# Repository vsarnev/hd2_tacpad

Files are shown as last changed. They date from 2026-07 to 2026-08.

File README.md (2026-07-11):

# HD2 Tacpad

> ***"Stratagems primed. For Super Earth. For Managed Democracy."***

A working **HELLDIVERS™ 2 Stratagem Tacpad**: a cosplay prop that's also a real stratagem input device. Punch your codes into the touchscreen and the Tacpad transmits them to your PC as keyboard input, complete with the sound effects, team voice callouts, and a **"REQUEST RECEIVED"** call-in reveal straight off the front lines.

Built on an affordable ESP32-S3 touchscreen, it pairs over **Bluetooth** as a wireless keyboard. It's an actual stratagem macropad that *also* looks the part strapped to your wrist on the drop.

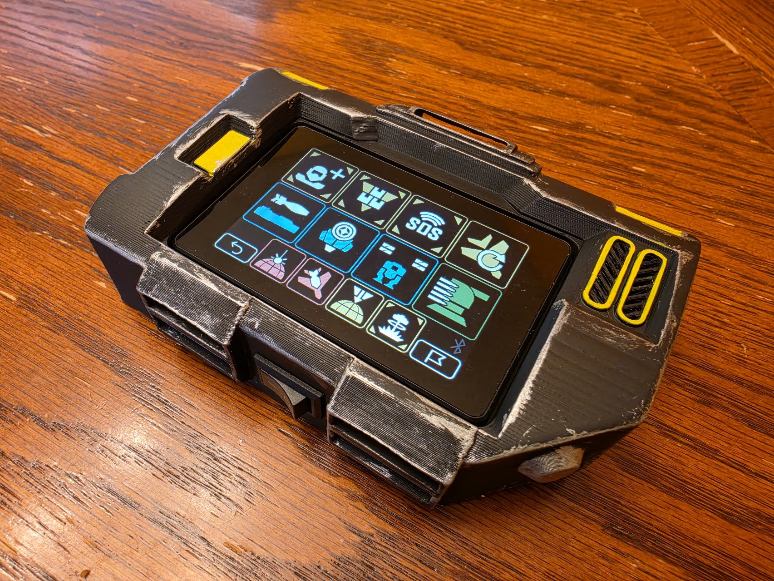
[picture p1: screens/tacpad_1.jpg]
The Tacpad


> [!NOTE]
> This is a **fork** of [unic8s/hd2_macropad](https://github.com/unic8s/hd2_macropad); see [Lineage & Credits](#lineage--credits). It runs on the specific device [JC3248W535](https://www.aliexpress.com/item/1005007566332450.html?) (a 3.5" ESP32-S3 QSPI touchscreen).
>
> **The assembled Tacpad connects over Bluetooth only**, since the enclosure covers the board's USB-C port. The firmware keeps USB support (inherited from the base project) for use on the bare board, e.g. for flashing.

## Contents

- [What this fork adds](#what-this-fork-adds)
- [Lineage & Credits](#lineage--credits)
- **Build Guide**
  - [1. Bill of Materials](#1-bill-of-materials)
  - [2. 3D Printed Parts](#2-3d-printed-parts)
  - [3. Electronics & Wiring](#3-electronics--wiring)
  - [4. Firmware](#4-firmware)
  - [5. Assembly](#5-assembly)
  - [6. Finished](#6-finished)
- [Get the game](#get-the-game) · [Disclaimer](#disclaimer)

---

## What this fork adds

Everything from the base firmware, plus a full front-line immersion layer:

- 🔊 **Helldivers SFX throughout.** Directional arrow tones, stratagem-prime cue, menu open/close, tab swipes. The original macropad sounds are swapped for in-universe audio.
- 📡 **Team voice callouts.** Your Super Destroyer and Eagle-1 announce stratagems by category with randomized lines, triggered on the call-in, exactly like in the field.
- 🖥️ **"REQUEST RECEIVED" call-in screen.** A full-screen reveal (icon + name) every time a stratagem is dispatched.
- 🎯 **Manual arm-mode input.** Hold the centre d-pad toggle to *open the stratagem menu* (it holds Ctrl on the host), then tap your code on the arrows. Each valid input is sent **live**, so the in-game menu builds as you type; complete a valid code and it throws + auto-disarms.
- ⚡ **Crisp, reliable touch input.** The panel's phantom double-taps are fixed at the source, so codes register cleanly even when spammed fast.
- 🔈 **Volume control** in settings and loudness-normalized audio across every cue and voice line.
- 🔋 **Battery level indicator.** For a LiPo-powered build, a battery icon + % up top and a voltage readout with on-device calibration, read through the ESP32's ADC.

Loadout selection, presets, user icons, cooldown tracking, ship-module modifiers, and BLE/USB switching all carry over from the base firmware.

---

## Lineage & Credits

This project stands on the shoulders of prior democratic contributions, so please support the originals:

- **Firmware base** is [unic8s/hd2_macropad](https://github.com/unic8s/hd2_macropad). All the core stratagem-input, loadout, preset, cooldown, and configuration machinery is theirs. This fork is an immersion + input-feel layer on top. Detailed device setup & configuration lives in their [Wiki](https://github.com/unic8s/hd2_macropad/wiki).
- **Physical Tacpad design** is [Senpaijeffa's *Helldivers 2 Tacpad*](https://makerworld.com/en/models/997088-helldivers-2-tacpad-with-touchscreen-for-cosplay#profileId-1437063) on MakerWorld, the 3D-printed prop this build is based on.
- **Stratagem icons** are [@nvigneux](https://github.com/nvigneux)'s [Helldivers 2 Stratagems SVG set](https://github.com/nvigneux/Helldivers-2-Stratagems-icons-svg).
- **Device demo/reference** is [@NorthernMan54](https://github.com/NorthernMan54)'s [JC3248W535EN project](https://github.com/NorthernMan54/JC3248W535EN).
- **UI & menu SFX** come from [Gromlon Props](https://github.com/gromprops/Helldivers-2-Stratagem-Tacpad); the interface, menu, and stratagem sound effects are from their Helldivers 2 Stratagem Tacpad project.
- **Voice lines** are HELLDIVERS™ 2 in-game audio, from the community clip collection shared on [r/Helldivers](https://www.reddit.com/r/Helldivers/comments/1c348h6/helldivers_2_short_audio_clips_here_for_your/) ([clips folder](https://drive.google.com/drive/folders/1VT6HKNjR-lEG9xjQJB1dwWCI1ufyEFug)).

**HELLDIVERS™ 2** is © Arrowhead Game Studios, published by Sony Interactive Entertainment. This is a non-commercial fan project and is not affiliated with either.

---

# Build Guide

How to build the physical Tacpad: gather the parts, print the shell, wire the electronics, flash the firmware, and close it up.

## 1. Bill of Materials

Part links are examples, not direct recommendations. You may find cheaper sources at local hobby stores, Amazon, etc.

### Electronics

| Qty | Part | Notes |
| :-: | --- | --- |
| 1 | [JC3248W535](https://www.aliexpress.com/item/1005007566332450.html?) | 3.5" ESP32-S3 QSPI touchscreen (the brains + display). |
| 1 | microSD card | For the audio assets. Any size works; the contents are only ~10 MB. |
| 2 | [3.7V 1100mAh LiPo cell](https://www.aliexpress.com/item/1005004304618610.html?) | Different sizes work too, as long as they fit the battery tray. |
| 1 | [TP4056 charging module](https://www.aliexpress.com/item/1005006904523567.html?) | LiPo charge management. If you can find one with CC1/CC2 wired for USB-C negotiation, let me know! Otherwise it charges from a USB-A-to-USB-C cable. Micro-USB modules also work. |
| 1 | [DC-DC step-up (boost) converter, 0.9-5V to 5V](https://www.aliexpress.com/item/1005003479999072.html?) | Boosts the 3.7 V LiPo to a stable 5 V. |
| 1 | [KCD1 latching power switch](https://www.aliexpress.com/item/32873386670.html?) | External on/off. |
| 2 | [10 kΩ resistor](https://www.aliexpress.com/item/1005007539842999.html?) | Battery-level voltage divider (optional; see [3d](#3d-battery-level-monitor-optional)). |

### Connectors

A generic [1.25 mm JST connector kit](https://www.aliexpress.com/item/1005008691681233.html?) plus the solder/crimp hardware makes disassembly much easier. Bare-minimum connectors:

| Qty | Connector | Use |
| :-: | --- | --- |
| 1 | 4P1.25 JST male | Power into the ESP32's power port. |
| 1 | 2P1.25 JST male | Speaker into the ESP32's speaker port. |
| 1 | 8P1.25 JST male | *(optional)* Battery-sense wire to GPIO7 for the battery monitor. |
| 2 | Male + female JST (any size) | Connect the LiPo cells to the TP4056. I used 2.5 mm. |

### Hardware

| Qty | Part | Notes |
| :-: | --- | --- |
| 4 | [M3x4x5mm heat-set insert](https://www.aliexpress.com/item/1005006071488810.html?) | Voron-standard inserts, for fastening the lid to the body. |
| 4 | M3x8 FCHS | Screws the lid onto the main body. |
| 3 | Generic Velcro strap | 2 straps on the bottom, 1 on top, for affixing to your cosplay/arm. |
| As needed | Hookup wire, solder, Kapton tape | For wiring and insulation. |

**Printed parts:** see [Section 2](#2-3d-printed-parts).

---

## 2. 3D Printed Parts

The shell is based on [Senpaijeffa's Helldivers 2 Tacpad](https://makerworld.com/en/models/997088-helldivers-2-tacpad-with-touchscreen-for-cosplay#profileId-1437063). The STLs for this build live in [`3d-print/`](3d-print/):

- [`3d-print/tacpad-body.stl`](3d-print/tacpad-body.stl) is the main body / enclosure.
- [`3d-print/tacpad-lid.stl`](3d-print/tacpad-lid.stl) is the lid.

**Print settings:** standard settings work for both parts. I recommend at least 2 walls, 15% infill, and 4 top/bottom layers. Supports are required on both, but I've kept them to a minimum: only the internal structure of the main body and the battery tray on the lid need them.

---

## 3. Electronics & Wiring

> [!IMPORTANT]
> The **wiring diagram is the source of truth**; the steps below are a walkthrough of it. If anything conflicts, trust the diagram.

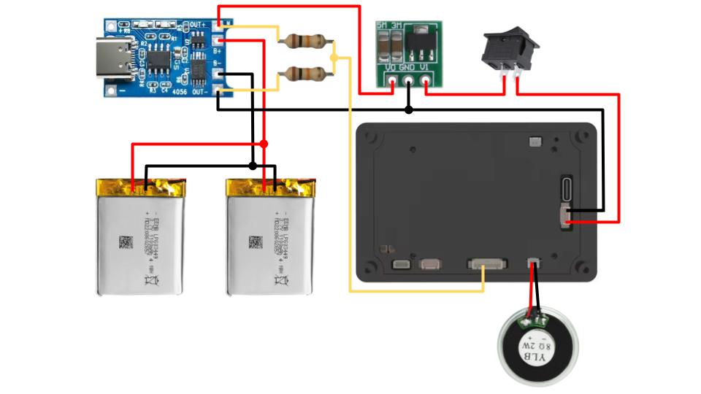
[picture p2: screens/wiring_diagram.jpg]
Wiring diagram


**Power flow at a glance:** the unit runs off two 3.7 V 1100 mAh LiPo cells (~6-7 hours of runtime) that feed the TP4056 charging module, so it can charge over USB whether it's switched on or not. The TP4056 feeds the DC-DC step-up converter, which supplies a stable 5 V to the Display through the power switch. The speaker wires straight to the speaker port, and an optional voltage divider taps the battery to GPIO7 for the on-screen battery monitor.

> [!WARNING]
> Before connecting the two batteries in parallel, make sure they're at a **reasonably similar charge**. Once wired together they'll balance their voltages, so a large difference between them can be hazardous.

| Step | Reference |
| --- | :-: |
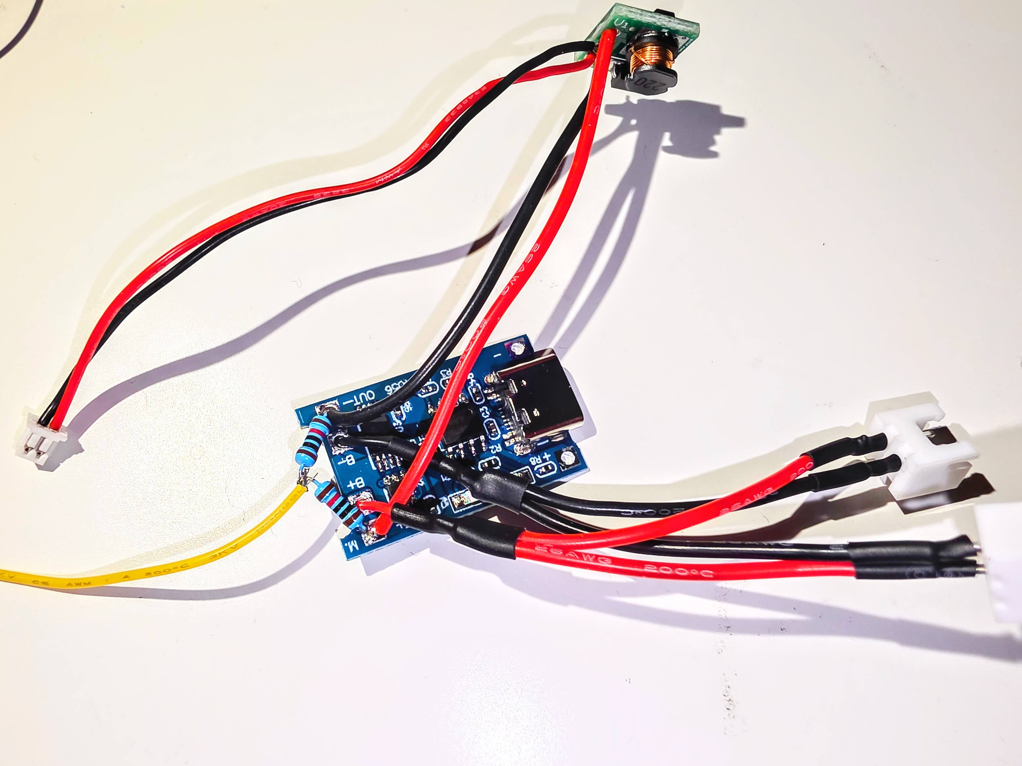
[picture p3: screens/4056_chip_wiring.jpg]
TP4056 + step-up wiring
| **3a. Battery, charging & boost.** Solder two 2-pin JST connectors in parallel onto the TP4056's **BAT+ / BAT-** pads (mind polarity, don't short anything), then plug a battery into each. Connect a USB cable to the TP4056 and confirm power at **OUT+ / OUT-** with a multimeter. Wire **OUT+ → the converter's V0** pad and **OUT- → GND**. *(If adding the battery monitor, solder the two 10 kΩ resistors to OUT+/OUT- now.)* Confirm ~5 V between the converter's **GND and V1** pads (mine reads ~5.4 V, which is fine). |  |
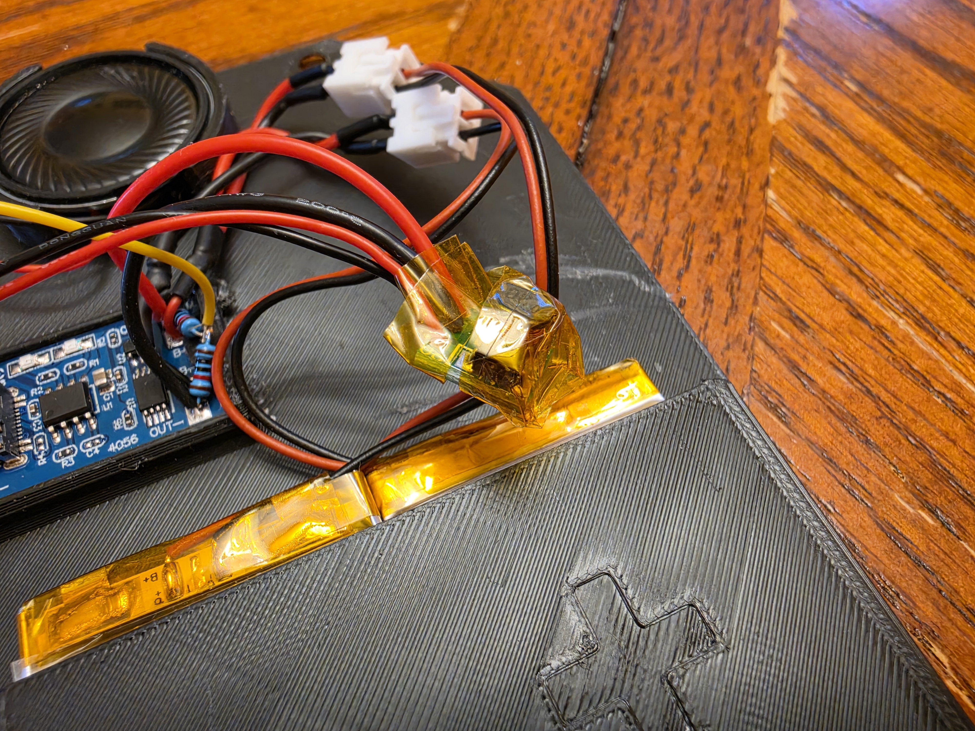
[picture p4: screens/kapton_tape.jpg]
Step-up insulated with Kapton tape
| **3a (cont.) 5 V feed + insulation.** Run a wire from the converter's **V1** pad (5 V out) and another from **GND** (either the converter's GND or the TP4056's OUT-); optionally terminate them in a 2P JST so the step-up is easy to disconnect. Then **insulate the converter with Kapton tape** so it can't short against anything. |  |
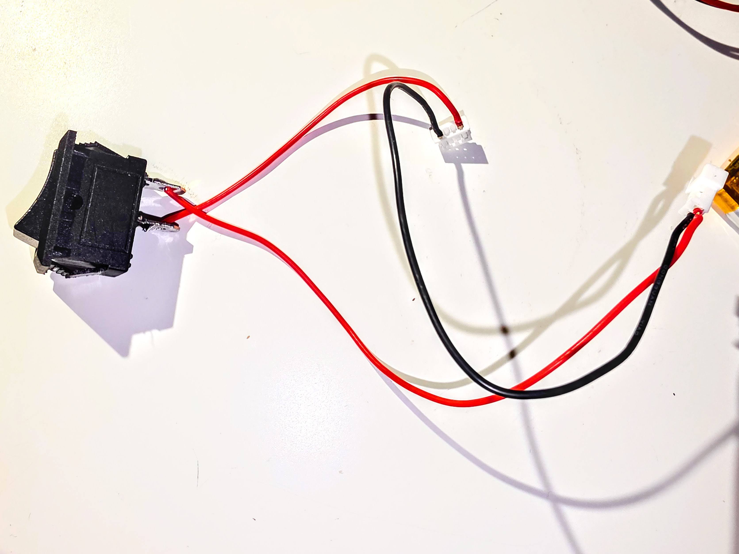
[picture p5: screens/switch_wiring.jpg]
Power switch wiring
| **3b. Rocker switch & power connector.** The converter's **V1 = VIN** and **GND = GND**. Wire both to the **4P1.25 power connector**, with the rocker switch **interrupting the VIN line**. Mind the Display's pin labeling. Plug it in (double-check polarity!), flip the switch, and confirm the unit powers on. |  |
| **3c. Speaker.** Wire the speaker to the **2P1.25 connector**, minding polarity per the diagram. The unit should play audio now. | |
| **3d. Battery level monitor** *(optional)*. Wire the two 10 kΩ resistors in series across **OUT+ and OUT-**, then take a tap off the midpoint. Route it to the **3rd pin of the 8P1.25 connector**, and double-check it lands on **GPIO7**. Calibrate on-screen later (settings → Misc). | See 3a |
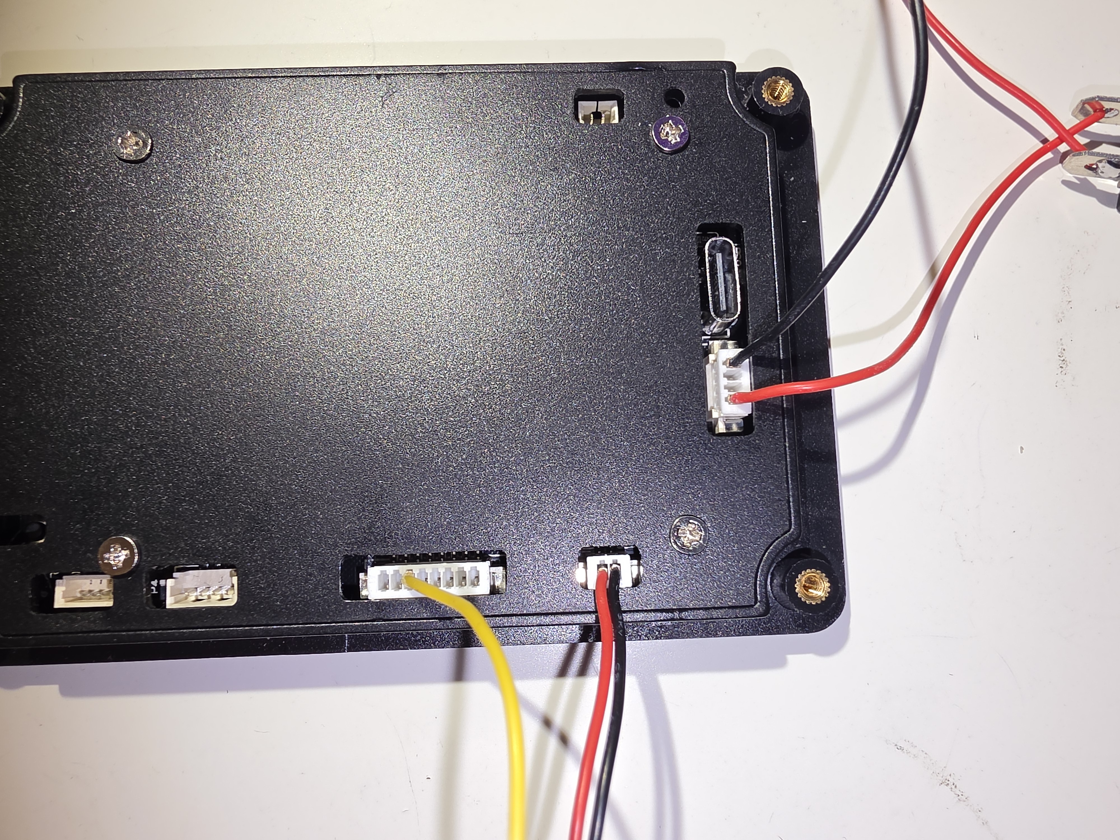
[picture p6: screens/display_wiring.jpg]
Display wiring
| **3e. Final wiring.** Your connectors going into the Display should look like this. |  |

---

## 4. Firmware

> [!WARNING]
> Never feed battery power and USB power into the Display at the same time. Switch the unit off before plugging in USB for flashing.

Flash the firmware with [PlatformIO](https://platformio.org/) (ESP-IDF / `espressif32`):

```sh
pio run -t upload
```

Then copy the contents of [`sdcard/`](sdcard/) to the root of a microSD card and insert it. The SD card holds **only the audio** (44.1 kHz / 16-bit / mono WAVs); the stratagem images are compiled into the firmware. On first boot, pair over **Bluetooth** and set your stratagem keybinding in settings (defaults to **Ctrl + WASD/arrow keys**).

Confirm everything works: sound plays on the speaker, the display is responsive, and the battery % reads about right. If you're using the battery monitor, fine-tune it by measuring the real voltage across OUT+/OUT- with a multimeter and adjusting the offset in **settings → Misc** until they match.

> [!TIP]
> For the base firmware's full configuration options, unic8s's [Wiki](https://github.com/unic8s/hd2_macropad/wiki) applies to this fork.

---

## 5. Assembly

> [!NOTE]
> Double-check the firmware is flashed before you start. Once assembled, the Display's USB-C connector is inaccessible. *(The converter has no Kapton tape in the photos below; I insulated it afterwards.)*

| Step | Reference |
| --- | :-: |
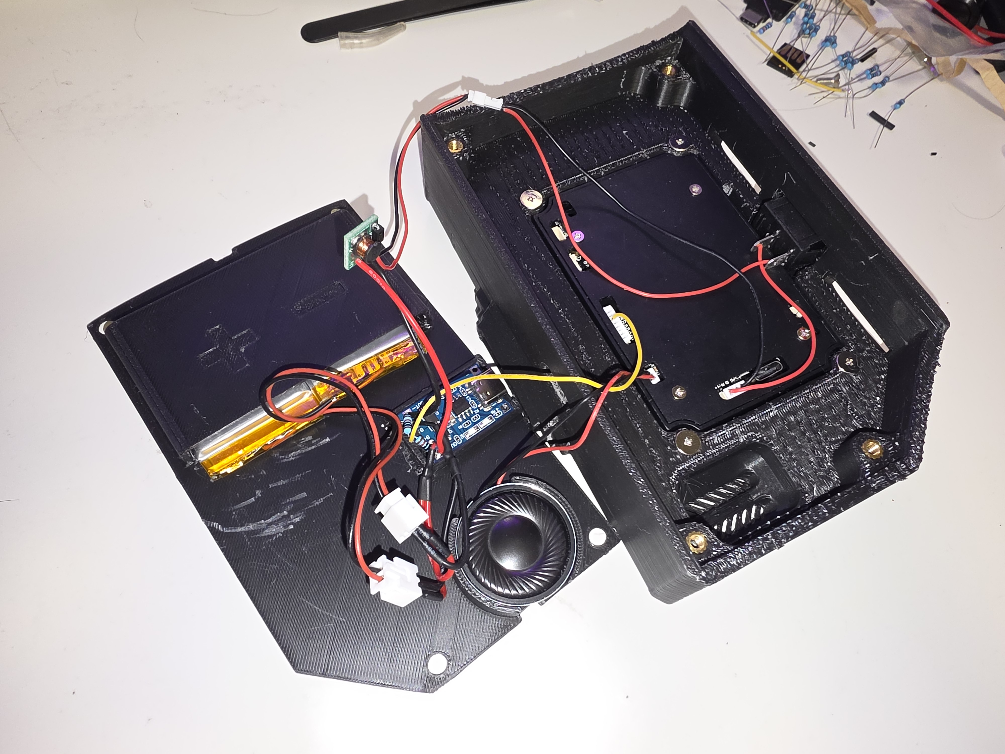
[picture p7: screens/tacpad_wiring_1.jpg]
Pre-assembly layout
| **Fit the electronics into the lid.** Slot the TP4056 into its space (a dab of glue helps if loose). Slot the speaker into its cutout, routing the wires out through the channel and inward, and fix it with glue. Install the two LiPo cells in the battery tray (I used a little double-sided adhesive so they don't slide, but can still be removed). |  |
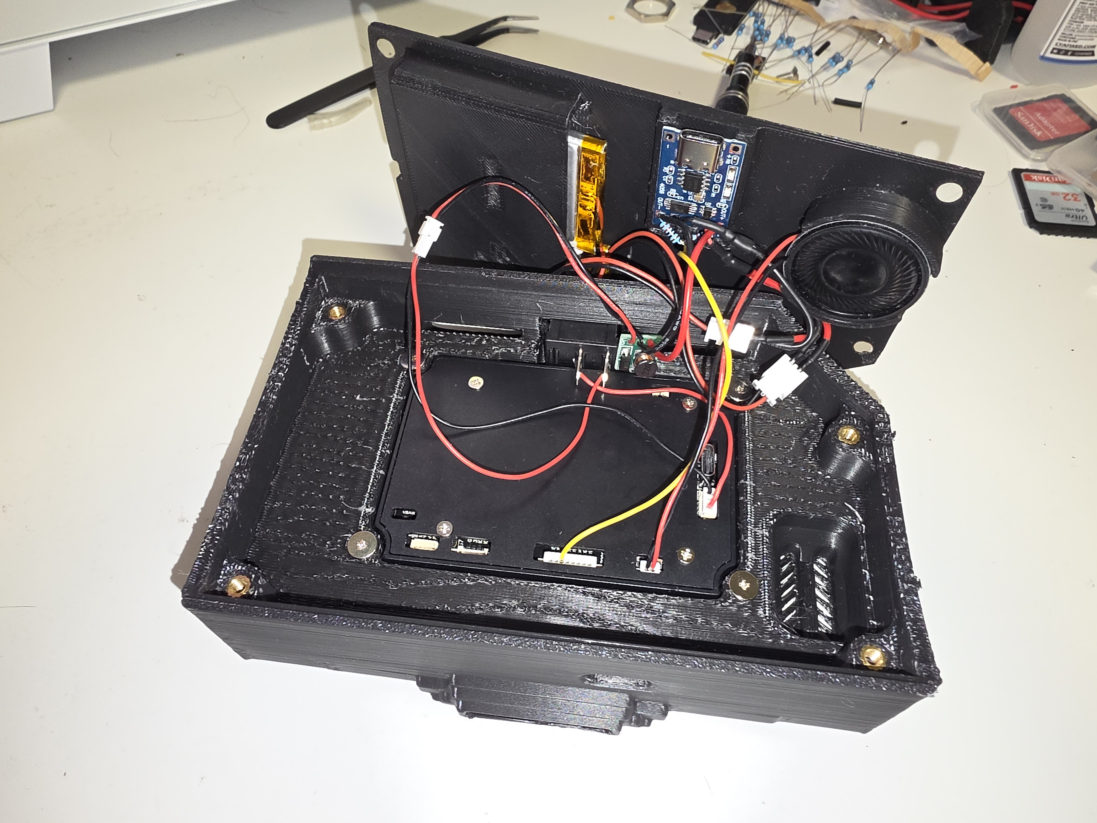
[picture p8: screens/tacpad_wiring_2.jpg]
Pre-assembly layout, alternate
| **Prep the main body.** Melt the 4 heat-set inserts into place with a soldering iron, then screw the Display in with the 4 screws, keeping its USB-C side next to the speaker hole so the screen is oriented correctly *(you can always flip it in settings)*. Drop the rocker switch into its slot, then wire everything up and give it one more test. |  |
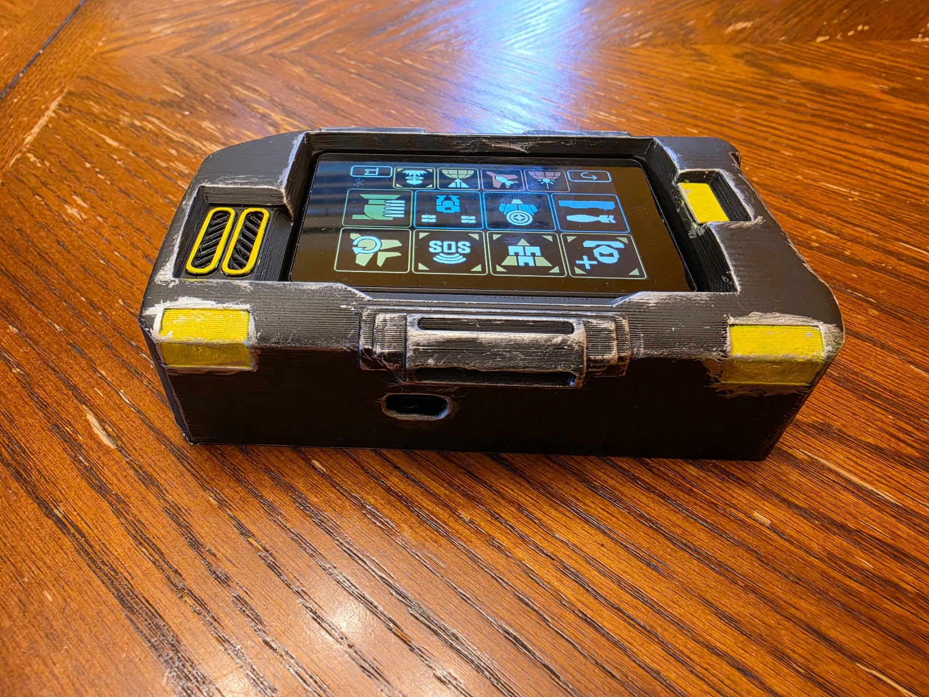
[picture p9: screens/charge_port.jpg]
Charging port aligned in its slot
| **Close it up.** Tuck the wires away (make sure nothing gets pinched), then fit the lid onto the back of the body, keeping the USB charging port lined up with its slot. Fasten with the 4 M3x8 FHCS, checking everything seats without much resistance. |  |

---

## 6. Finished

Congratulations on your finished Tacpad, Helldiver! Use the 3 Velcro strap points to attach it to your cosplay (or wherever you like), or leave it as-is as a display piece.

To charge, plug a USB-C cable into the back: the inside glows red while charging and switches to blue/green once full (check your charging module's exact colour scheme). If the port doesn't quite fit a cable, sand the opening a little to widen it.

| | |
| :-: | :-: |
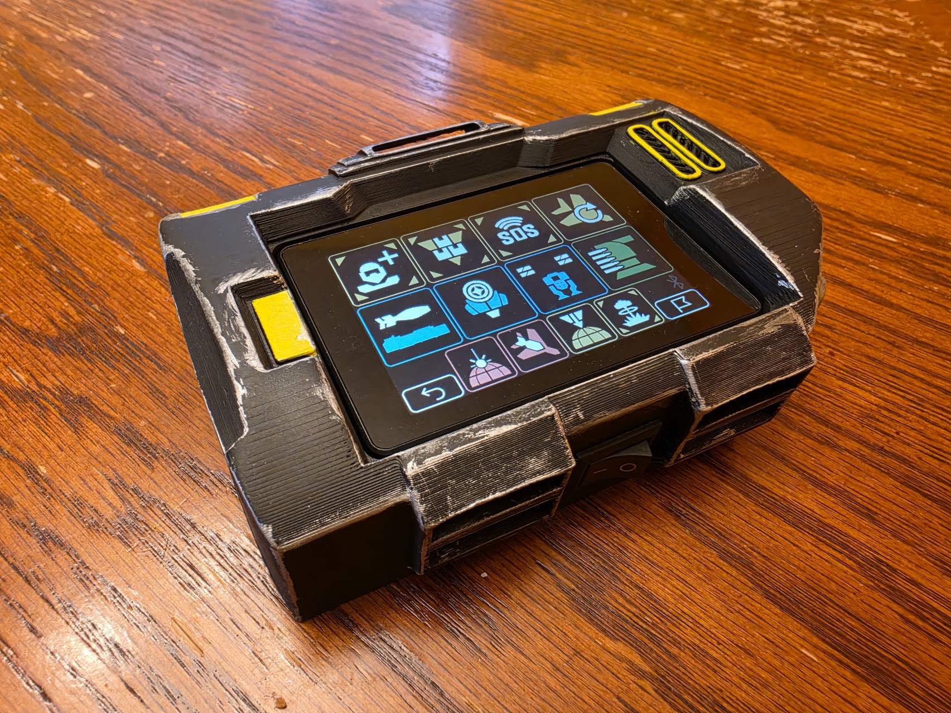
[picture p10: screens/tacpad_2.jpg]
Finished Tacpad
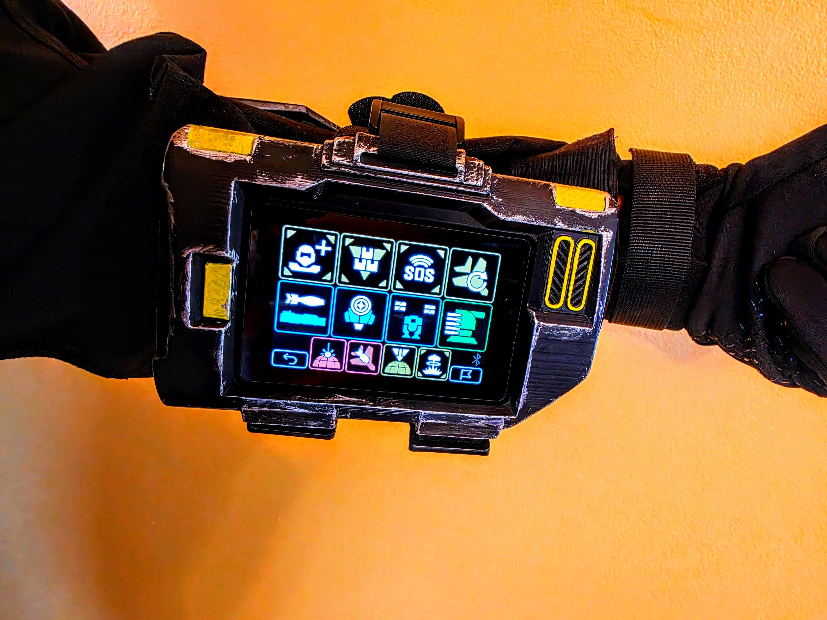
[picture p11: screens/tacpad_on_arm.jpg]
Tacpad worn on the arm
|  |  |

**For Super Earth!**

---

## Get the game

[HELLDIVERS™ 2 on Steam](https://store.steampowered.com/app/553850/HELLDIVERS_2/) · [PlayStation™](https://www.playstation.com/games/helldivers-2/)

## Disclaimer

> This is a private, open-source, non-commercial fan project and is not associated in any way with Sony Interactive Entertainment LLC or Arrowhead Game Studios. HELLDIVERS™ and PlayStation™ are registered trademarks of Sony Interactive Entertainment LLC. Assets in this project are either produced for free non-commercial use or published by the owners credited above.

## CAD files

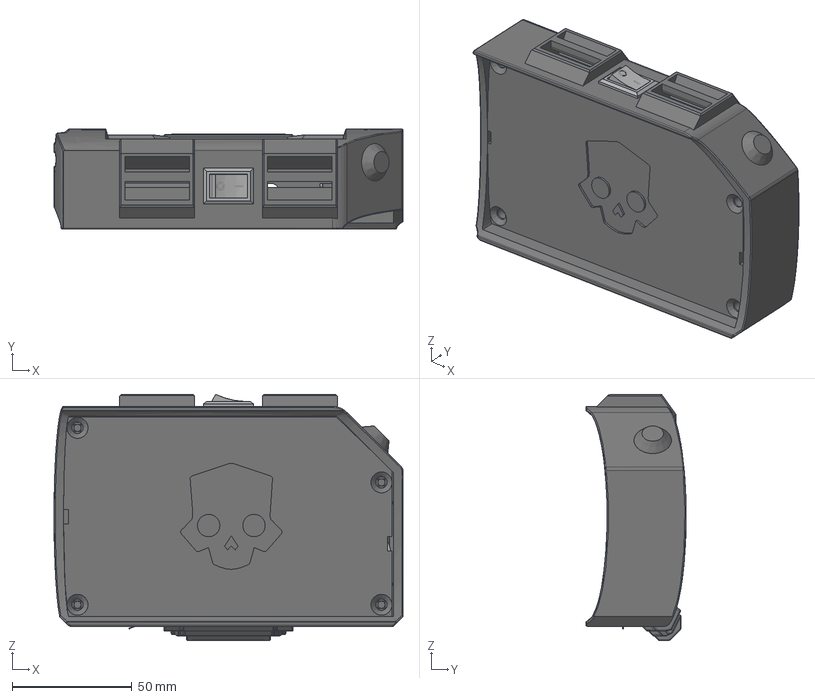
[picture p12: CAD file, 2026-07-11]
3d-print/Helldivers Tacpad.step
146.0 x 42.0 x 103.0 mm
JC3248W535 Display
Helldiver+tacpad+lid+v6 v5
2W Speaker
board
USB_Type_C_Connector
8205A_2045
DW01-P
small1005_smd_resistor x 2
small1005_smd_resistor (1)
small1005_smd_capacitor
smd_capacitor
SOP-8_4056E
solder_dot_round
solder_dot_round (1)
solder_dot_round (2)
solder_dot_round (3)
small1005_smd_capacitor (1)
LED2
LED2 (1)
small1005_smd_resistor (2)
small1005_smd_resistor (4) x 2
soldering
Bateria LiPo 3.7V 1000mA 503450
Bateria LiPo 3.7V 1000mA 503450_1
Blade_001
Blade_002
Base_w_text
knob001

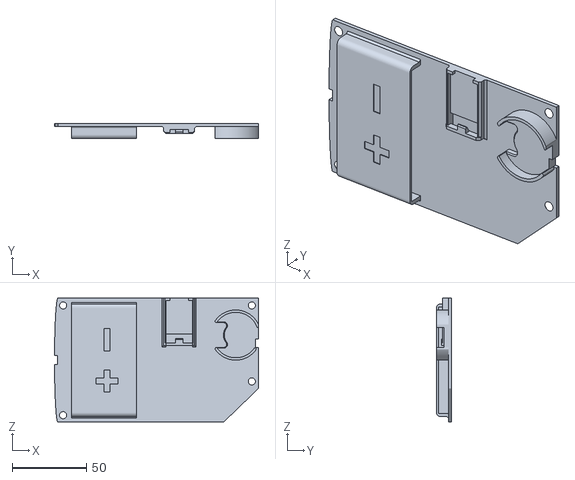
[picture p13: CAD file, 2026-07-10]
3d-print/tacpad-lid.stl
137.5 x 10.3 x 83.4

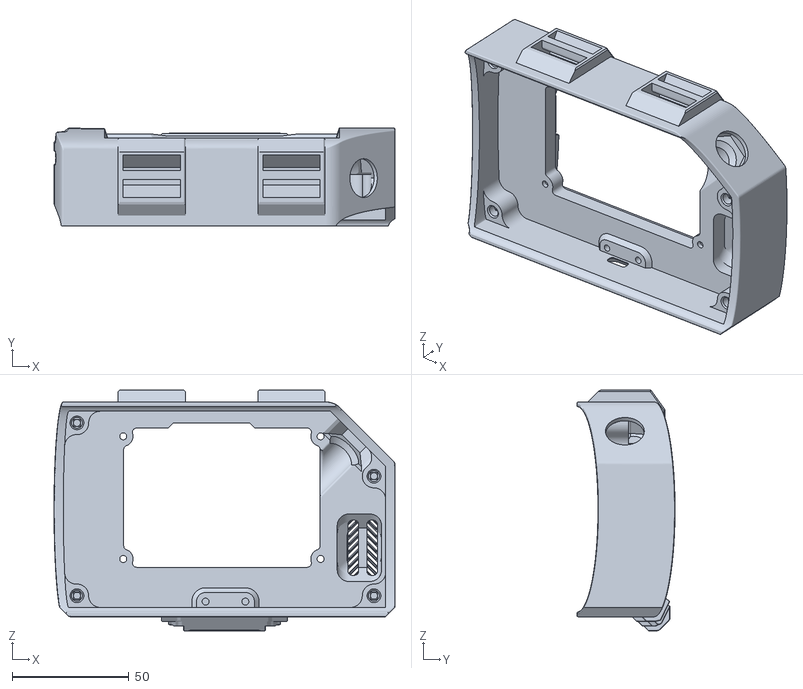
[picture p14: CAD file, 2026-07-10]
3d-print/tacpad-body.stl
146.0 x 42.0 x 103.0

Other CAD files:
3d-print/Helldivers Tacpad.f3z

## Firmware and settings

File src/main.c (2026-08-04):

#include <lvgl.h>
#include "display.h"
#include "esp_bsp.h"
#include "lv_port.h"
#include <esp_system.h>
#include <ui/ui.h>
#include <ui/vars.h>
#include <ui/screens.h>
#include <ui/actions.h>
#include <ui/images.h>
#include <ui/ui_events.h>
#include <ui/ui_post.h>
#include "hid_dev.h"
#include "i2s_player.h"
#include "ble/ble_controller.h"
#include "usb/usb_controller.h"
#include "configuration.h"
#include "keymaps.h"
#include "main.h"

// Connection type
uint8_t connectionType = CT_NONE;

// Flag for ready state of LVGL after init
bool lvglReady = false;

// Stratagem code sequence (buffer) for execution
uint8_t stratagemCode[MAX_CMD_LENGTH];
// Stratagem mask for modifier key combination (ctrl, alt, etc.)
uint8_t stratagemMask;

// Flag for sound playback state
bool soundPlayback = false;
// Path to sound file which should be played
char *soundFile;
// Flag for muting sound playback
bool playerMuted;
// Set true to abort the currently-playing sound (so a new press's sound starts immediately)
volatile bool soundInterrupt = false;
// Software master volume, 0..256 (256 = full). Set from the config slider, applied in the player.
volatile uint16_t audioVolume = 256;

// Delay for HID input execution in milliseconds (default: 100)
int inputDelay = 100;

bool manualAutoComplete = true;
bool showCooldowns = false;
bool gameAfterPreset = false;

// Rotation of screen (default: 90)
int screenRotation = LV_DISP_ROT_90;

extern lv_obj_t *cooldownLabels[MAX_USER_STRATAGEMS];
extern uint32_t cooldownValues[MAX_USER_STRATAGEMS];
uint16_t lastCooldownDiffs[MAX_USER_STRATAGEMS];

lv_timer_t *cooldownTimer;

// Set stratagem code sequence which should be executed
// sequence - keycode buffer
// mask - modifier keys
// plain - resolve via keymap or send directly (raw)
void setStratagemCode(uint8_t sequence[MAX_CMD_LENGTH], uint8_t mask, bool plain)
{
  switch (connectionType)
  {
  case CT_BLUETOOTH:
    if (!ble_connected())
    {
      return;
    }
    break;
  case CT_USB:
    if (!usb_connected())
    {
      return;
    }
    break;
  default:
    return;
  }

  uint8_t sequenceLength = 0;

  for (uint8_t c = 0; c < MAX_CMD_LENGTH; c++)
  {
    if (sequence[c] > 0)
    {
      uint8_t rawCode = sequence[c];
      stratagemCode[c] = plain ? rawCode : LookupKeycode(rawCode);
      sequenceLength++;
    }
    else
    {
      break;
    }
  }

  stratagemMask = mask;
}

// Playback sound file from specified path
// path - path to the sound file
void playbackSound(char *path)
{
  soundFile = path;
  soundInterrupt = true; // cut any sound currently playing so this one starts right away
  soundPlayback = true;
}

// Dim the screen to a specific value
// brightness - A brightness value between 0 and 100 (percent)
void dimScreen(int brightness)
{
  bsp_display_brightness_set(brightness);
}

// Update UI relating to connection state
void updateConnection()
{
  if (!lvglReady)
  {
    return;
  }

  lv_img_dsc_t *imgConnection;

  switch (connectionType)
  {
  case CT_BLUETOOTH:
    // Check bluetooth connection state
    if (ble_connected())
    {
      imgConnection = (lv_img_dsc_t *)&img_btcon;
    }
    else
    {
      imgConnection = (lv_img_dsc_t *)&img_btdis;
    }
    break;
  case CT_USB:
    // Check USB connection state
    if (usb_connected())
    {
      imgConnection = (lv_img_dsc_t *)&img_us_bcon;
    }
    else
    {
      imgConnection = (lv_img_dsc_t *)&img_us_bdis;
    }
    break;
  default:
    return;
  }

  lv_obj_set_style_bg_img_src(objects.img_connection1, imgConnection, LV_PART_MAIN | LV_STATE_DEFAULT);
  lv_obj_set_style_bg_img_src(objects.img_connection2, imgConnection, LV_PART_MAIN | LV_STATE_DEFAULT);
}

// Delay for checking if a the stratagem execution buffer is filled
#define INPUT_CHECK_DELAY 5

// Manual "arm" mode: the UI task asks the HID task to hold the stratagem modifier (Ctrl) down —
// opening the in-game stratagem menu — or to release it (closing/throwing). Routing it through the
// HID task keeps every HID report on one task, so it can never race the sequence burst below.
// PULSE = release then re-hold, i.e. reset the in-game menu (used when a wrong input clears a
// partially-entered code so the pad and the game stay in sync).
enum { HID_ARM_NONE = 0, HID_ARM_HOLD, HID_ARM_RELEASE, HID_ARM_PULSE };
static volatile int hidArmRequest = HID_ARM_NONE;
static volatile uint8_t hidArmMask = 0;

// Live-key ring buffer: individual keystrokes sent while armed (modifier held) so the in-game
// stratagem menu builds as the user taps, instead of one burst at the very end.
#define HID_LIVE_QUEUE_LEN 16
static volatile uint8_t hidLiveQueue[HID_LIVE_QUEUE_LEN];
static volatile uint8_t hidLiveHead = 0;
static volatile uint8_t hidLiveTail = 0;

void hidHoldModifier(uint8_t mask)
{
  hidArmMask = mask;
  hidArmRequest = HID_ARM_HOLD;
}

void hidReleaseModifier(void)
{
  hidArmRequest = HID_ARM_RELEASE;
}

void hidPulseModifier(uint8_t mask)
{
  hidArmMask = mask;
  hidArmRequest = HID_ARM_PULSE;
}

void hidSendLiveKey(uint8_t mask, uint8_t keycode)
{
  hidArmMask = mask; // the modifier is held across live keys
  uint8_t next = (hidLiveTail + 1) % HID_LIVE_QUEUE_LEN;
  if (next == hidLiveHead)
  {
    return; // queue full (never at human tap speed) — drop
  }
  hidLiveQueue[hidLiveTail] = keycode;
  hidLiveTail = next;
}

// Task for exeuction of HID inputs
void hid_input_task(void *pvParameters)
{
  while (1)
  {
    vTaskDelay(INPUT_CHECK_DELAY / portTICK_PERIOD_MS);

    // Resolve the active HID sender once per tick; skip the tick if nothing is connected (do NOT
    // return — that would kill the task permanently and no input would ever send again).
    void (*fptr)(unsigned char, unsigned char, unsigned char);

    switch (connectionType)
    {
    case CT_BLUETOOTH:
      fptr = &ble_keyboard_send;
      break;
    case CT_USB:
      fptr = &usb_keyboard_send;
      break;
    default:
      // Nothing connected: drop pending requests so nothing fires stale on reconnect.
      hidArmRequest = HID_ARM_NONE;
      hidLiveHead = hidLiveTail;
      continue;
    }

    double inputDelayPeriod = inputDelay / portTICK_PERIOD_MS;

    // Drain live keystrokes first (modifier stays held via hidArmMask), so a key tapped just before
    // an arm request is delivered ahead of the hold/release/pulse below.
    while (hidLiveHead != hidLiveTail)
    {
      uint8_t key = hidLiveQueue[hidLiveHead];
      hidLiveHead = (hidLiveHead + 1) % HID_LIVE_QUEUE_LEN;

      fptr(hidArmMask, key, 1);
      vTaskDelay(inputDelayPeriod);
      fptr(hidArmMask, key, 0); // mask kept — the modifier stays held
      vTaskDelay(inputDelayPeriod);
    }

    // Service a pending arm request: hold the modifier (open menu), release it (close/throw), or
    // pulse it (release then re-hold to reset the menu after a wrong input).
    if (hidArmRequest != HID_ARM_NONE)
    {
      if (hidArmRequest == HID_ARM_PULSE)
      {
        fptr(0, 0, 0);
        vTaskDelay(inputDelayPeriod);
        fptr(hidArmMask, 0, 0);
      }
      else
      {
        fptr(hidArmRequest == HID_ARM_HOLD ? hidArmMask : 0, 0, 0);
      }
      hidArmRequest = HID_ARM_NONE;
    }

    if (stratagemCode[0] > 0)
    {
      uint8_t cmdIndex = 0;

      // Press the modifier (Ctrl) first, then walk the sequence pressing/releasing each key.
      fptr(stratagemMask, 0, 0);
      vTaskDelay(inputDelayPeriod);

      while (stratagemCode[cmdIndex] > 0 && cmdIndex < MAX_CMD_LENGTH)
      {
        fptr(stratagemMask, stratagemCode[cmdIndex], 1);
        vTaskDelay(inputDelayPeriod);
        fptr(stratagemMask, stratagemCode[cmdIndex], 0);
        vTaskDelay(inputDelayPeriod);

        stratagemCode[cmdIndex] = 0;
        cmdIndex++;
      }

      // Release everything (this final Ctrl-up is what throws the stratagem — and, in arm mode,
      // is the auto-disarm after a completed code).
      fptr(0, 0, 0);
    }
  }
}

// Dedicated audio task: plays queued sounds immediately (low latency), and because playbackSound
// sets soundInterrupt, a new press cuts the current sound so rapid inputs produce rapid beeps.
void audio_task(void *pvParameters)
{
  while (1)
  {
    if (soundPlayback && lvglReady)
    {
      soundPlayback = false;
      soundInterrupt = false;

      if (!playerMuted)
      {
        play_wav(soundFile);
      }
    }
    else
    {
      vTaskDelay(2 / portTICK_PERIOD_MS);
    }
  }
}

// Task for exeuction of EEZ Flows
void flow_tick_task()
{
  ui_tick();
}

void ui_update_task()
{
  if (!lvglReady)
  {
    return;
  }

  bool activeTimer = false;

  for (uint8_t c = 0; c < MAX_USER_STRATAGEMS; c++)
  {
    uint32_t cooldownValue = cooldownValues[c];
    lv_obj_t *cooldownLabel = cooldownLabels[c];
    int16_t diff = cooldownValue - getNow();

    if (cooldownValue > 0 && diff > 0)
    {
      activeTimer = true;

      if (lastCooldownDiffs[c] == diff)
      {
        continue;
      }

      lastCooldownDiffs[c] = diff;

      uint8_t min = 0;
      uint16_t sec = diff;

      while (sec >= 60)
      {
        min++;
        sec -= 60;
      }

      char *textCooldown = (char *)malloc(8 * sizeof(char));
      sprintf(textCooldown, "%d:%02d", min, sec);

      lv_label_set_text(cooldownLabel, (void *)textCooldown);

      if (lv_obj_has_flag(cooldownLabel, LV_OBJ_FLAG_HIDDEN))
      {
        lv_obj_clear_flag(cooldownLabel, LV_OBJ_FLAG_HIDDEN);
      }
    }
    else
    {
      cooldownValues[c] = 0;

      if (!lv_obj_has_flag(cooldownLabel, LV_OBJ_FLAG_HIDDEN))
      {
        lv_obj_add_flag(cooldownLabel, LV_OBJ_FLAG_HIDDEN);
      }
    }
  }

  if(!activeTimer && !cooldownTimer->paused){
    lv_timer_pause(cooldownTimer);
  }
}

// App main function
void app_main()
{
  // Init and load config from NVS storage
  initConfig();

  // Setup HID input task (async)
  xTaskCreatePinnedToCore(&hid_input_task, "hid_input_task", 2048, NULL, 5, NULL, 0);

  // Dedicated audio task so sound playback never blocks HID sends and fires with minimal latency
  xTaskCreatePinnedToCore(&audio_task, "audio_task", 4096, NULL, 5, NULL, 1);

  // Resolve screen rotation from config
  screenRotation = peekConfig("rotation", LV_DISP_ROT_90);

  // Display configuration
  bsp_display_cfg_t cfg = {
      .lvgl_port_cfg = ESP_LVGL_PORT_INIT_CONFIG(),
      .buffer_size = HD2MP_LCD_QSPI_H_RES * HD2MP_LCD_QSPI_V_RES,
      .rotate = screenRotation,
  };

  // Init display
  bsp_display_start_with_config(&cfg);
  // Turn of display backlight
  bsp_display_backlight_off();

  // Lock the mutex due to the LVGL APIs are not thread-safe
  bsp_display_lock(0);

  // Start LVGL
  ui_init();
  // UI post processing
  ui_post();

  // Release the mutex
  bsp_display_unlock();

  vTaskDelay(200 / portTICK_PERIOD_MS);

  // Turn on display backlight
  bsp_display_backlight_on();

  // Setup cooldown timer
  cooldownTimer = lv_timer_create(ui_update_task, 1000, NULL);
  cooldownTimer->repeat_count = -1;
  lv_timer_pause(cooldownTimer);

  // Read config
  loadConfig();

  lvglReady = true;

  // Preload the rapid-tap arrow SFX into PSRAM so each press plays instantly (no per-sound SD open,
  // which was the startup latency that made fast presses feel like they queued up).
  preload_wav(SND_ARR_UP);
  preload_wav(SND_ARR_DOWN);
  preload_wav(SND_ARR_LEFT);
  preload_wav(SND_ARR_RIGHT);

  // Playback intro sound
  playbackSound(SND_INTRO);

  updateConnection();
  updateStratagemSelection();
  updatePresets();

  // Setup timer for EEZ Flow ui tick
  lv_timer_t *flowTickTimer = lv_timer_create(flow_tick_task, 10, NULL);
  flowTickTimer->repeat_count = -1;
}

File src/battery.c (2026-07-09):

#include "battery.h"
#include "esp_adc/adc_oneshot.h"
#include "esp_adc/adc_cali.h"
#include "esp_adc/adc_cali_scheme.h"
#include "esp_log.h"
#include <lvgl.h>
#include "ui/ui.h"
#include "ui/screens.h"
#include "ui/styles.h"
#include "main.h"
#include "configuration.h"

static const char *TAG_BAT = "Battery";

// --- Wiring ---------------------------------------------------------------------------------------
// battery+  --[ Rtop ]--+--[ Rbottom ]-- GND      (tap = the junction -> GPIO7)
//                       |
//                     GPIO7  (ADC1_CH6)
//
// Set BATT_DIVIDER_RATIO to (Rtop + Rbottom) / Rbottom. Equal resistors (e.g. 10k/10k) = 2.0.
#define BATT_DIVIDER_RATIO 2.0f

// Coarse gain trim (compile-time). Runtime fine-tuning is done on-screen with the +/- buttons, which
// adjust an additive offset stored in NVS — no reflash needed.
#define BATT_CAL_TRIM 1.0253f

#define BATT_ADC_CHANNEL ADC_CHANNEL_6 // GPIO7 = ADC1_CH6 on the ESP32-S3
#define BATT_ADC_ATTEN ADC_ATTEN_DB_12 // ~0..3.1V input range
#define BATT_SAMPLES 96                // averaged per reading (heavy, since there's no smoothing cap)
#define BATT_UPDATE_MS 15000           // battery moves slowly; poll gently
#define BATT_CAL_KEY "battcal"         // NVS key for the runtime calibration offset (mV)
#define BATT_CAL_STEP_MV 10            // each +/- tap nudges by 0.01 V
#define BATT_CAL_LIMIT_MV 500          // clamp the offset to a sane range

static adc_oneshot_unit_handle_t s_adc = NULL;
static adc_cali_handle_t s_cali = NULL;
static bool s_caliValid = false;
static int s_calOffsetMv = 0;
static int s_lastMv = 0;

static lv_obj_t *s_topLabel = NULL;    // battery icon + % at the top of the config screen
static lv_obj_t *s_voltLabel = NULL;   // voltage readout in the Misc tab
static lv_obj_t *s_offsetLabel = NULL; // current calibration offset, between the -/+ buttons

// Resting-voltage(mV) -> %% for a 1S LiPo. Coarse but far better than a straight line. Interpolated.
static int lipoPercent(int mv)
{
    static const int curve[][2] = {
        {4200, 100}, {4150, 95}, {4110, 90}, {4080, 85}, {4020, 80},
        {3980, 75}, {3950, 70}, {3910, 65}, {3870, 60}, {3850, 55},
        {3840, 50}, {3820, 45}, {3800, 40}, {3790, 35}, {3770, 30},
        {3750, 25}, {3730, 20}, {3710, 15}, {3690, 10}, {3610, 5}, {3300, 0}};
    const int n = sizeof(curve) / sizeof(curve[0]);

    if (mv >= curve[0][0])
    {
        return 100;
    }
    if (mv <= curve[n - 1][0])
    {
        return 0;
    }
    for (int i = 0; i < n - 1; i++)
    {
        const int vHi = curve[i][0], pHi = curve[i][1];
        const int vLo = curve[i + 1][0], pLo = curve[i + 1][1];
        if (mv <= vHi && mv >= vLo)
        {
            return pLo + (mv - vLo) * (pHi - pLo) / (vHi - vLo);
        }
    }
    return 0;
}

static const char *battSymbol(int pct)
{
    if (pct >= 85)
    {
        return LV_SYMBOL_BATTERY_FULL;
    }
    if (pct >= 60)
    {
        return LV_SYMBOL_BATTERY_3;
    }
    if (pct >= 35)
    {
        return LV_SYMBOL_BATTERY_2;
    }
    if (pct >= 10)
    {
        return LV_SYMBOL_BATTERY_1;
    }
    return LV_SYMBOL_BATTERY_EMPTY;
}

int batteryMillivolts(void)
{
    if (s_adc == NULL)
    {
        return 0;
    }

    int64_t sum = 0;
    int valid = 0;
    for (int i = 0; i < BATT_SAMPLES; i++)
    {
        int raw;
        if (adc_oneshot_read(s_adc, BATT_ADC_CHANNEL, &raw) == ESP_OK)
        {
            sum += raw;
            valid++;
        }
    }
    if (valid == 0)
    {
        return 0;
    }

    const int rawAvg = (int)(sum / valid);
    int pinMv = 0;
    if (s_caliValid)
    {
        adc_cali_raw_to_voltage(s_cali, rawAvg, &pinMv);
    }
    else
    {
        pinMv = rawAvg * 3100 / 4095; // rough fallback if hardware calibration is unavailable
    }

    s_lastMv = (int)(pinMv * BATT_DIVIDER_RATIO * BATT_CAL_TRIM) + s_calOffsetMv;
    return s_lastMv;
}

int batteryPercent(void)
{
    return lipoPercent(batteryMillivolts());
}

// Refresh both readouts from a single fresh reading.
static void batt_refresh(void)
{
    const int mv = batteryMillivolts();
    const int pct = lipoPercent(mv);

    if (s_topLabel != NULL)
    {
        lv_label_set_text_fmt(s_topLabel, "%s %d%%", battSymbol(pct), pct);
    }
    if (s_voltLabel != NULL)
    {
        lv_label_set_text_fmt(s_voltLabel, "%d.%02d V", mv / 1000, (mv % 1000) / 10);
    }
    if (s_offsetLabel != NULL)
    {
        lv_label_set_text_fmt(s_offsetLabel, "%+d mV", s_calOffsetMv);
    }
}

static void batt_update_timer(lv_timer_t *t)
{
    (void)t;
    batt_refresh();
}

// Runtime one-point calibration: nudge the reading by +/- 0.01 V per tap, persisted to NVS.
static void batt_cal_nudge(int deltaMv)
{
    s_calOffsetMv += deltaMv;
    if (s_calOffsetMv > BATT_CAL_LIMIT_MV)
    {
        s_calOffsetMv = BATT_CAL_LIMIT_MV;
    }
    if (s_calOffsetMv < -BATT_CAL_LIMIT_MV)
    {
        s_calOffsetMv = -BATT_CAL_LIMIT_MV;
    }
    setConfigBig(BATT_CAL_KEY, (uint16_t)s_calOffsetMv);
    batt_refresh();
}

static void batt_cal_minus_cb(lv_event_t *e)
{
    (void)e;
    batt_cal_nudge(-BATT_CAL_STEP_MV);
}

static void batt_cal_plus_cb(lv_event_t *e)
{
    (void)e;
    batt_cal_nudge(+BATT_CAL_STEP_MV);
}

// Load the saved calibration offset from NVS. Must be called after the config NVS handle is open,
// i.e. from loadConfig() — NOT from initBatteryMonitor(), which runs in ui_post() before loadConfig
// opens the handle (reading it there always returned the default 0, so the offset never persisted).
void batteryLoadCalibration(void)
{
    int mv = getConfigBig(BATT_CAL_KEY, 0);
    if (mv > BATT_CAL_LIMIT_MV)
    {
        mv = BATT_CAL_LIMIT_MV;
    }
    if (mv < -BATT_CAL_LIMIT_MV)
    {
        mv = -BATT_CAL_LIMIT_MV;
    }
    s_calOffsetMv = mv;
    batt_refresh();
}
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

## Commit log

2026-07-07 Helldivers 2 tacpad overhaul: input, sound, call-in screen, voice lines
    - Manual input: reliable + low-latency. Touch-bounce double-clicks fixed at the
    source (45ms release bridge over the flickery AXS15231B panel). Instant
    error-reset on invalid codes. Bastion 9-input code fixed.
    - Sound: Helldivers SFX throughout (menus, nav, tabs, selection); loudness
    normalized; software volume slider in config; original repo sounds removed.
    - Voice callouts: Super Destroyer / Eagle 1 lines mapped by category with
    randomization, triggered from the call-in reveal.
    - REQUEST RECEIVED full-screen reveal (icon + name) on stratagem fire, across
    the manual / game / mission input paths.
    - Manual scree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
    [configuration.h]
2026-07-07 Manual arm/disarm mode + settings-menu sounds
    - Manual arm toggle in the d-pad centre: arming holds Ctrl (opens the in-game
    stratagem menu) and unlocks the arrows; a completed code fires and auto-disarms
    (its own Ctrl-up is the throw); manual disarm releases Ctrl; leaving the screen
    force-disarms so Ctrl never sticks. Arrows are inert + dimmed until armed. The
    toggle shows an up-chevron, dark when locked / gold when armed.
    - HID output is now single-threaded: the UI requests a Ctrl hold/release and
    hid_input_task performs it, so the arm toggle can't race the code-send burst.
    Also fixed a latent bug there where a disconnected state killed the task
    permanently (return -> continue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
    [main.c]
2026-07-07 Code cleanup: remove dead code, trim debug logging, fix stale comments
    - Delete dead lookupManualSequence() (zero callers; superseded by
    matchManualSequence) and the dead updateBatteryInfo() declaration.
    - Drop the HID hot-path debug logs and the now-unused TAG/esp_log.h in main.c;
    remove dead includes (esp_flash, esp_chip_info, esp_heap_caps, driver/gpio).
    - Trim per-read/per-write NVS logging in configuration.c and per-playback
    success logging in i2s_player.c (keep the error branches).
    - Remove unused TAG_EVT and three unused SND_* macros.
    - Fix stale/inaccurate comments (the "swipe surface" that was never wired, the
    "2ms" tick that's 5ms, i2s typos) and the misleading "generated b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
    [main.c]
2026-07-07 Commit the matching eez-flow engine (fixes clean-checkout build)
    The generated screens.c uses the newer EEZ flow font API (ext_font_desc_t,
    eez_flow_init_fonts, 5-arg eez_flow_init_themes), but the matching eez-flow
    amalgamation was never committed — it only ever existed as an uncommitted
    working-tree change, so a fresh checkout of this repo could not compile.
    Restore the correct engine from the EEZ Studio amalgamation (eez-framework
    commit 10f714f, May 2026) and re-apply this project's integration tweaks:
    <lvgl.h> include path and LZ4/SHA256 options off.
2026-07-07 Manual arm mode: send keystrokes live as the code is tapped
    Instead of accumulating the code and bursting it on completion, each valid arrow
    is now sent to the host the instant it is tapped (Ctrl held by arm), so the
    in-game stratagem menu builds in real time. Completion just releases Ctrl (the
    throw); a wrong input pulses Ctrl (release + re-hold) to reset the in-game menu
    in sync with the pad's instant error reset. Only valid keys ever reach the game.
    - main.c: live-key ring buffer drained by hid_input_task; HID_ARM_PULSE for the
    menu reset; queue/request cleared on disconnect.
    - ui_events.c: send LookupKeycode(dir) live on valid input; finalize releases
    (fire) or pulses (reset) instea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
    [main.c]
2026-07-08 Rewrite README for the HD2 Tacpad fork
    Reframe around the cosplay Tacpad with a feature list of the fork's additions
    (Helldivers SFX, team voice callouts, call-in screen, live arm-mode input,
    input-reliability work). Add prominent Lineage & Credits: unic8s (firmware base),
    Senpaijeffa (physical MakerWorld design), Gromlon Props (UI SFX), the r/Helldivers
    voice clip collection, plus the retained upstream icon/demo credits. Include the
    hardware photo.
2026-07-09 Add battery monitor; remove manual autocomplete; silence boot clicks
    Battery monitor (src/battery.c/.h):
    - ADC1 on GPIO7 reads a 1S LiPo through an external voltage divider (ratio a
    #define; default 2.0 for an even pair like 10k/10k), 96-sample averaged with
    curve-fitting calibration.
    - Settings screen: a battery icon + % at the top-right (tab bar narrowed to make
    room), and a voltage readout on the Misc tab with runtime +/- calibration
    (0.01 V steps) plus a live offset display. Calibration persists in NVS.
    - Fixes a load-order bug: the offset is loaded in loadConfig() (NVS handle open),
    not ui_post() which runs before the handle opens.
    Remove the "Auto-complete for manual" settin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
    [configuration.h]
2026-07-09 README: document the battery-level indicator + GPIO7 wiring
    Add the battery indicator to the feature list and a 'Battery monitor (optional)'
    subsection: voltage-divider wiring to GPIO7 (ADC1_CH6 on the P2 header), the
    BATT_DIVIDER_RATIO define, the never-wire-raw-battery warning, and the on-device
    calibration. Also drop the now-stale tacpad.jpg TODO comment.
2026-07-09 README: Bluetooth-only for the assembled prop; SD holds audio only
    The enclosure covers the USB-C port, so the built Tacpad connects over Bluetooth
    (the firmware keeps USB for the bare board). Also correct the asset docs: the SD
    card holds only the sounds; stratagem images are compiled into the firmware, not
    loaded from the card (there is no sdcard/assets/img).
2026-07-10 Add build guide, wiring/build photos, and 3D print STLs
    - BUILD.md: draft build guide structured around the wiring diagram + photos
    (power/charging via TP4056 + step-up, switch, USB-C charge-in, display wiring,
    optional battery divider, assembly, firmware). BOM + 3D-print settings + detailed
    assembly steps are marked TODO for the next pass.
    - screens/: 11 build photos (wiring diagram, TP4056/step-up, kapton insulation,
    switch, charge port, display wiring, pre-assembly, finished, on-arm).
    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
    [tacpad-body.stl, tacpad-lid.stl]
2026-07-11 BUILD: revise build guide (BOM with links, connectors, corrected wiring)
    Fill out the bill of materials with part links, connectors, and hardware; expand
    and correct the electronics/wiring steps (battery balancing warning, TP4056 ->
    step-up -> switch -> power connector, speaker, battery divider) and print settings.
2026-07-11 BUILD: polish phrasing and clarity in the build guide
    Light editorial pass over the instructions: fix comma splices, run-ons, and a
    typo; reduce repetition; and tighten the wiring steps (3a/3d) that read a bit
    cluttered. No technical changes - all pad names, connectors, part links, and
    warnings are unchanged.
2026-07-11 docs: merge build guide into README (BOM + build-step tables)
    Fold BUILD.md into the README so the whole project lives in one place, following
    the common GitHub hardware-project convention. Restructure the build sections
    A4T-style: BOM as scannable tables (qty/part/notes with links), and the wiring
    and assembly steps as two-column instruction+photo tables so each image sits
    beside its step. Add a table of contents. Remove the standalone BUILD.md.
2026-07-11 docs: pin in-table build photos to a fixed width
    The build photos range from ~1700px to 4000px wide; in Markdown tables GitHub
    renders each at native size, so higher-res shots (notably tacpad_on_arm.jpg in
    section 6) rendered much larger than their neighbours. Convert every in-table
    image to an <img width="400"> tag for uniform sizing; the standalone hero and
    wiring diagram keep full-width Markdown syntax. Full-res is still one click away.
2026-07-11 Add Design files
    [Helldivers Tacpad.f3z, Helldivers Tacpad.step]
2026-07-19 Cleanup code, rename vars, change intro timer
